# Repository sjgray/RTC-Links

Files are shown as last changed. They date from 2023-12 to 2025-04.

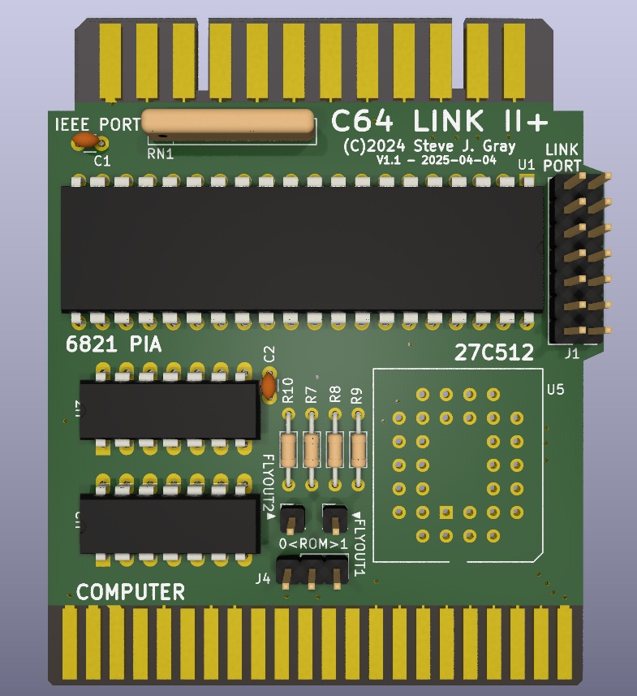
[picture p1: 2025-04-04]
RTC-Link2plus/V1.1/_pics/render.jpg

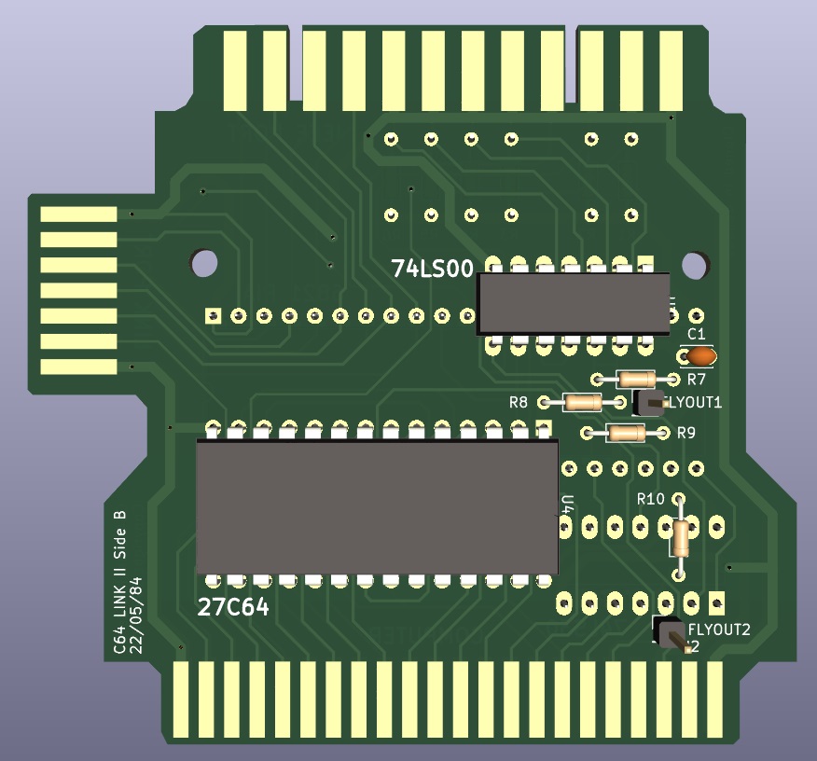
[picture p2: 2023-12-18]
RTC-Link2/_Pics/2023-12-04-render-back.jpg

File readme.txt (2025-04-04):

RTC Link Devices
================

http://www.cbmsteve.ca/
http://www.cbmsteve.ca/rtclinks/index.html

This is a project to clone and improve the Richmond Telecommunications ("RTC") Devices.

RTC released several different devices including:

* V-Link for VIC-20
* V-Link "64" for C64
* Link for C64
* Link-II for C64
* Mult-Link for C64

I personally own both a Link and Link-II, which I would like to clone. I have started with
the Link-II as it has the most features of the two. Also, the Link-II uses a single PCB
with components on both sides.

Link-II
-------

This is a single PCB with components on both sides. It was done this way to make the PCB
as small as possible so it could fit inside an AMP connector shell. There are two flyouts
that are connected internally into the C64 to make the Link more "transparent" which means
that IO and ROM are invisible when not in use. The Link-II also seems to work without these
connections but might have conflicts with other hardware or software.

First step was to de-solder all the components and scan each side. I then flipped the back-side
scan. Kicad was loaded and a new project created. I then loaded the front side and flipped
back-side as images and then added the components. I added global labels for the busses For the
address and data lines etc. I placed the components in their proper places then traced over the
traces on the images to connect the pins, updating labels where necessary.

Status: I will no be ordering PCB's of this design right away. I am concentrating on the PLUS
        version first as it will be easier to populate

Link-II Plus
------------

Once the Link-II was reverse engineered I decided to make a new version but with all components
on the same side making the board easier to build. I replaced the DIP EPROM with a PLCC version,
and some resistors with a resistor network in order to save space. I also replaced the Link
edge-connector with a pin header to allow a more common IDC ribbon cable.

Status: I ordered some V1.0 PCBs. On testing I discovered an error with resistor R9. This was
        corrected manually on the PCB and the board was tested to work properly.
        The design was updated to V1.1 and boards will be made. This should work correctly.        

Future
------

I would like to clone the original Link design but it uses a double-pcb design. I think the
original design would be ok for most people.

Thank-you
---------

Thanks to Walter Miraglia for helping me test and debug RTC-Link II+ V1.0!

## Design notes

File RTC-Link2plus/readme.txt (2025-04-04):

RTC-Link II Plus by Steve J. Gray
================

The RTC-Link II was an IEEE Cartridge for the Commodore C64. It enhanced
C64 BASIC by adding the extra disk commands of BASIC V4, plus a full
machine-language monitor. It also adds a "Link" port which enables
multiple computers to access IEEE devices on a sort-of "network".

The original cartridge is a small and simple IEEE interface using a
single PIA chip. To keep the device small it has components on both
sides of the PCB and is able to be mounted inside an AMP connector shell.

This "plus" version is a re-design that retains the same PCB size but with
all components on one side for an easier build. It retains its small size
by using a PLCC EPROM and resistor pack to reduce the component footprints.
Instead of using an edge connector for the "Link" port this version uses
a normal header. There is an option to have two different firmware
revisions, selectable with a jumper.

Pictures/info can be found at: http://www.cbmsteve.ca/rtclinks/
The GitHub repository is here: https://github.com/sjgray/RTC-Links

History
-------

V1.0 - 2023-12-04 Initial design prototype.
V1.1 - 2025-04-04 Fix for R9. To be tested.

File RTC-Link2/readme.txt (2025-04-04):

RTC-Link II Clone  Reverse Engineered by Steve J. Gray
=================

This is a clone of the RTC-Link II IEEE Cartridge for the Commodore C64.
It also enhances C64 BASIC by adding the extra disk commands of 
Commodore BASIC V4, as well as adding a full machine-language monitor.

The cartridge is a small and simple IEEE interface using a single PIA
chip. To keep the device small it packs in the chip on both sides of the
PCB and is able to be mounted inside an AMP connector shell.

KICAD was used to create a PCB that is very similar to the original and
mounts the components on both sides. I have also created a "plus" version
of the design that retains the same pcb size but with components on one
side, using a PLCC EPROM and resistor pack to reduce the component
footprints. It can also be found on this GitHub repository.

Pictures/info can be found at: http://www.cbmsteve.ca/rtclinks/
The GitHub repository is here: https://github.com/sjgray/RTC-Links

History
-------

V1.0 - 2023-12-04 Initial design prototype. Not tested.
V1.1 - 2025-04-04 Fix for R9. To be tested.

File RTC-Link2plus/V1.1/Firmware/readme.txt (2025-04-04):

RTC Link II Firmware
====================

The Link II+ board supports two different firmware sets in
a 64K EPROM, selectable via the J4 jumper.

The following files are available:

* RTCLINK2.BIN     - Original 8K firmware
* RTCLINK2-MOD.BIN - Modded 8K firmware with alternate power-on message
* RTCLINK2-64K.BIN - Full 64K binary with both sets above.
                     J4: 0=Original, 1=Modded

If you never plan on using a second firmware set you can just burn
either of the first two above to the EPROM and use a jumper wire
to short J4 pin 0 to pin1.

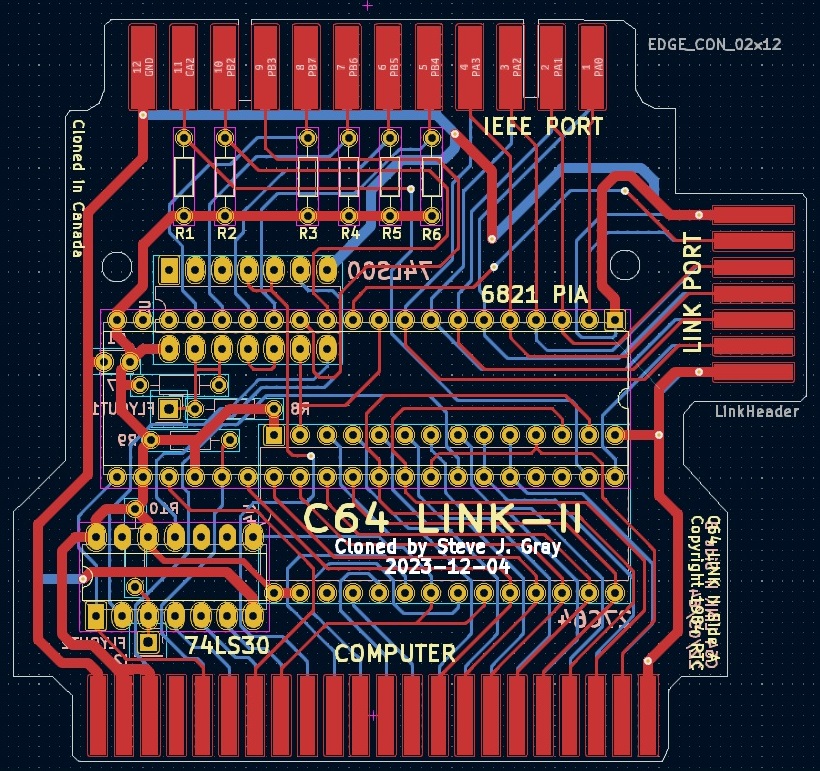
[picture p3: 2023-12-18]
RTC-Link2/_Pics/2023-12-04-routed.jpg

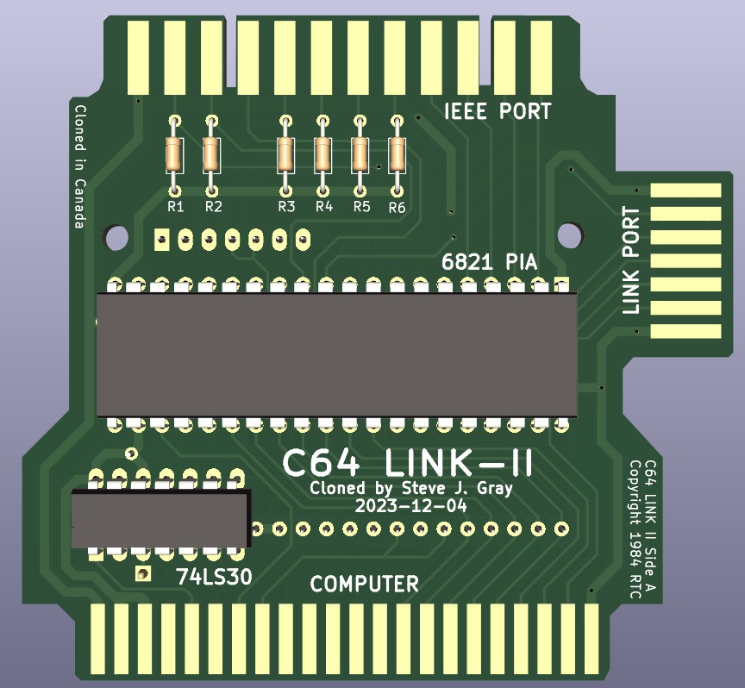
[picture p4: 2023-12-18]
RTC-Link2/_Pics/2023-12-04-render-front.jpg

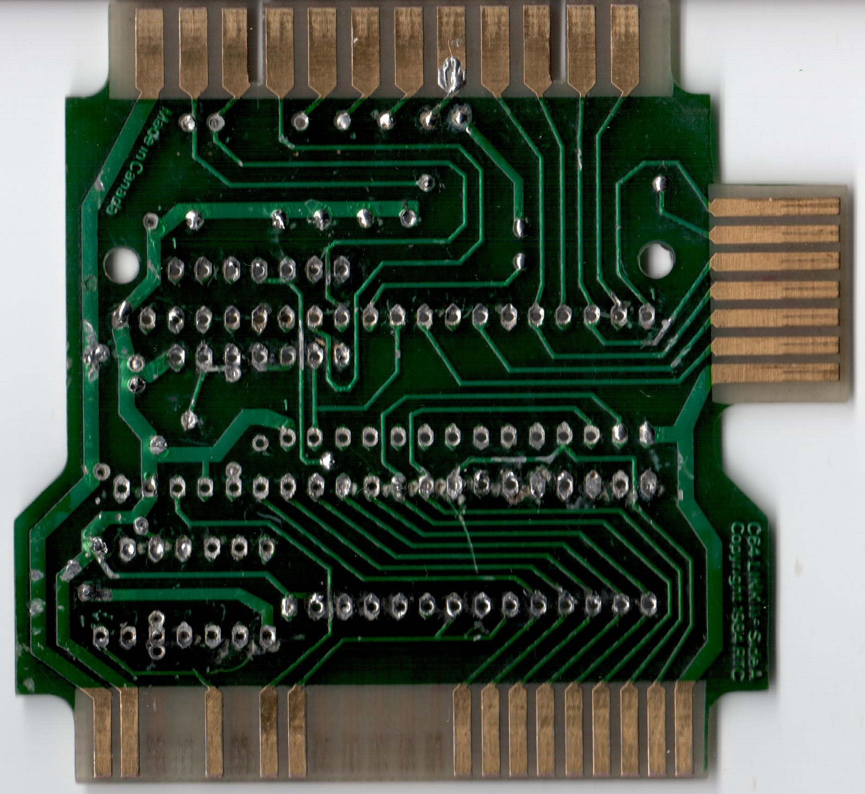
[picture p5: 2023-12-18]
RTC-Link2/rtclink2-pcb-a.jpg

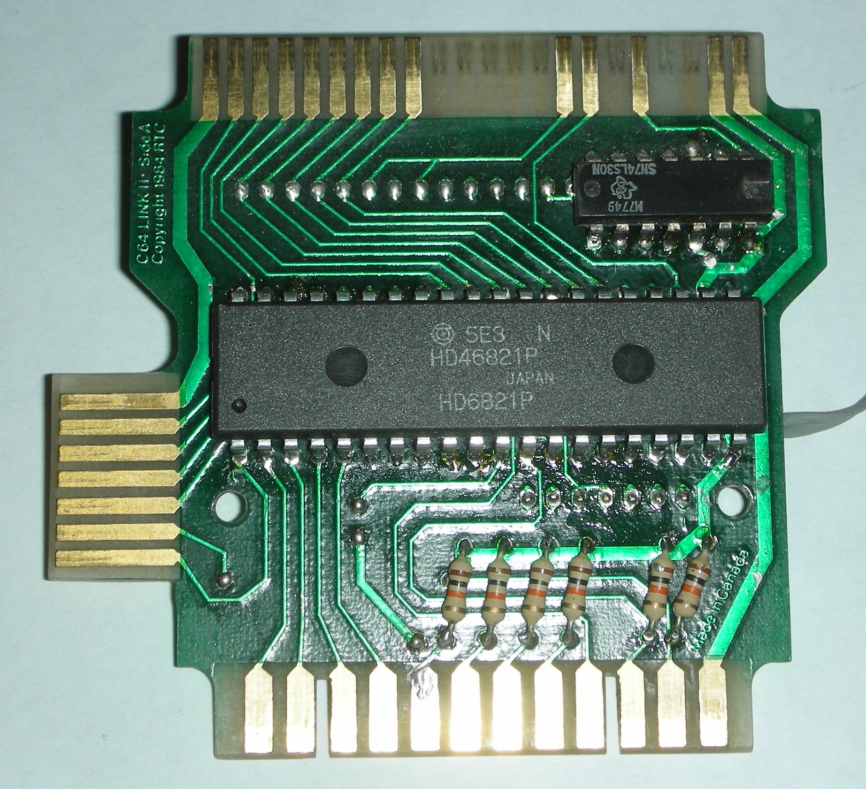
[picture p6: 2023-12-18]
RTC-Link2/rtclink2-top.jpg

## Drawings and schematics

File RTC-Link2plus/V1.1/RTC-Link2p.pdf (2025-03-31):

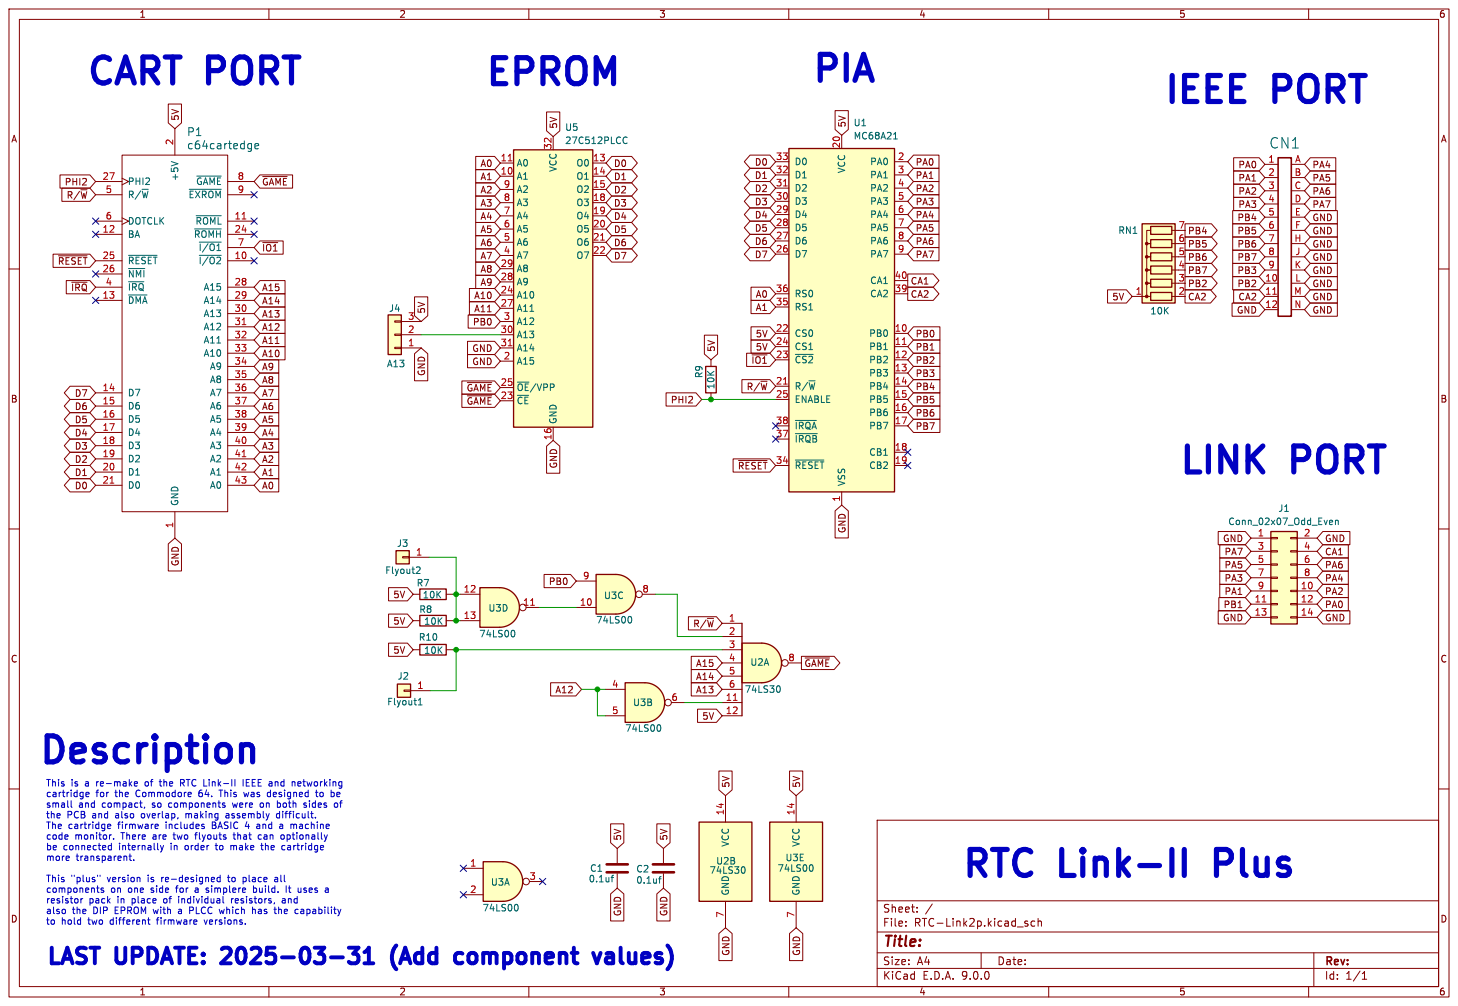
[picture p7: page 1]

IEEE PORT CART PORT

1 ~{GAME} 8 ~{EXROM} 9 ~{ROML}11 ~{ROMH}24 ~{I/O1} 7 ~{I/O2} 10 A15 28 A14 29 A13 30 A12 31 A11 32 A10 33 A9 34 A8 35 A7 36 A6 37 A5 38 A4 39 A3 40 A2 41 A1 42 A0 43 P1

Id: 1/1 Title: File: RTC-Link2p.kicad_sch Sheet: / C1

also the DIP EPROM with a PLCC which has the capability

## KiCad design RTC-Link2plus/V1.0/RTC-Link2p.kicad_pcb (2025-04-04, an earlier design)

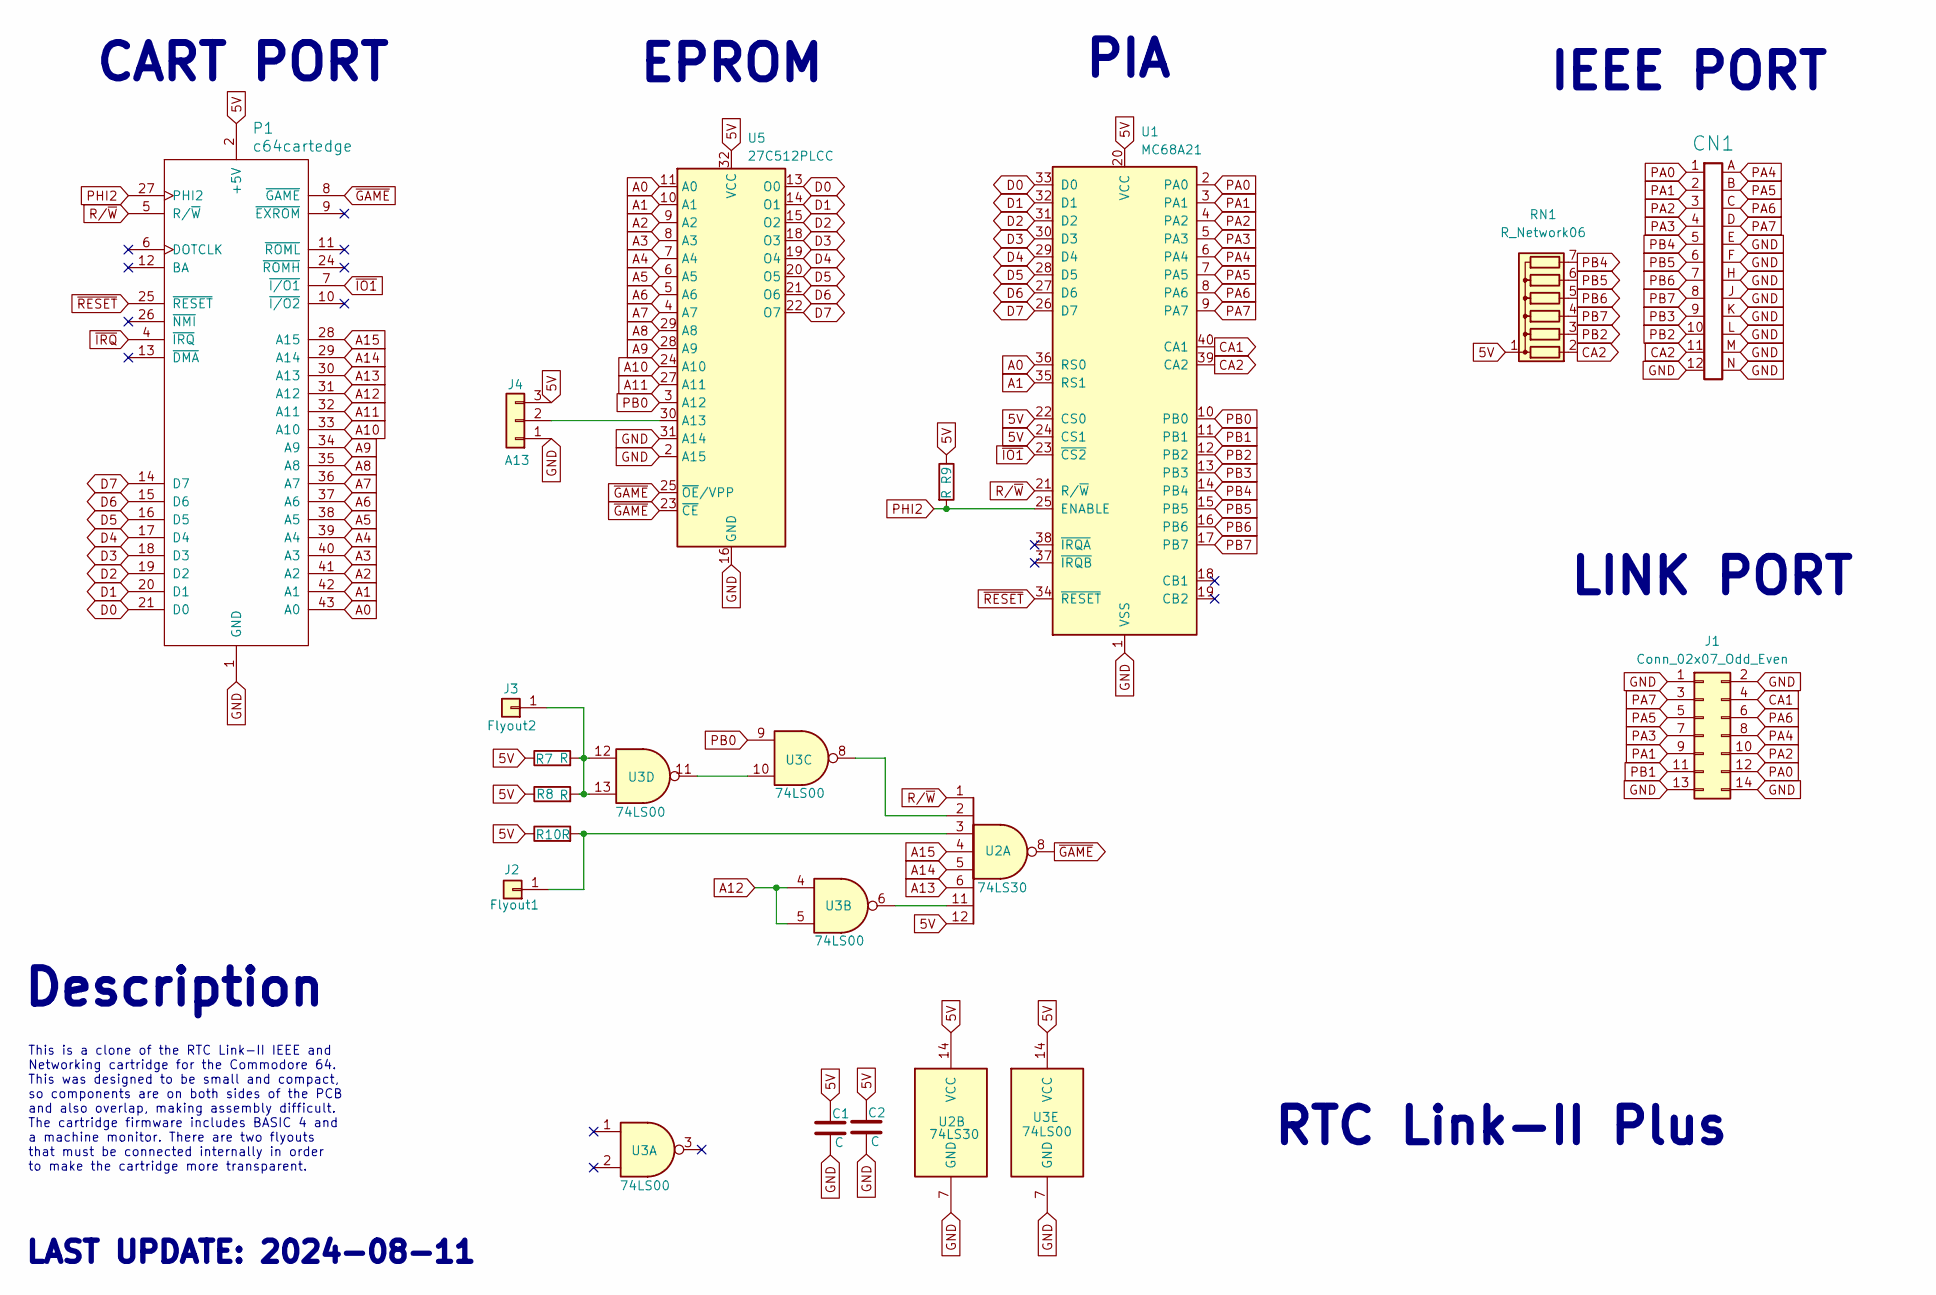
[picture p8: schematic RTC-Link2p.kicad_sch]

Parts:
C1, C2: C; C_Disc_D3.0mm_W1.6mm_P2.50mm
CN1: EDGE_CON_02x12; petieee
J1: Conn_02x07_Odd_Even; PinHeader_2x07_P2.54mm_Vertical
J2: Flyout1; PinHeader_1x01_P2.54mm_Vertical
J3: Flyout2; PinHeader_1x01_P2.54mm_Vertical
J4: A13; PinHeader_1x03_P2.54mm_Vertical
P1: c64cartedge
R7, R8, R9, R10: R; R_Axial_DIN0204_L3.6mm_D1.6mm_P7.62mm_Horizontal
RN1: R_Network06; R_Array_SIP7
U1: MC68A21; DIP-40_W15.24mm
U2: 74LS30; DIP-14_W7.62mm_LongPads
U3: 74LS00; DIP-14_W7.62mm_LongPads
U5: 27C512PLCC; PLCC-32_THT-Socket

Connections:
5V: C1.1, C2.1, J4.3, P1.2 (+5V), P1.3 (+5V), R7.1, R8.1, R9.1, R10.1, RN1.1 (common), U1.20 (VCC), U1.22 (CS0), U1.24 (CS1), U2.12, U2.14 (VCC), U3.14 (VCC), U5.32 (VCC)
A0: P1.43 (A0), U1.36 (RS0), U5.11 (A0)
A1: P1.42 (A1), U1.35 (RS1), U5.10 (A1)
A2: P1.41 (A2), U5.9 (A2)
A3: P1.40 (A3), U5.8 (A3)
A4: P1.39 (A4), U5.7 (A4)
A5: P1.38 (A5), U5.6 (A5)
A6: P1.37 (A6), U5.5 (A6)
A7: P1.36 (A7), U5.4 (A7)
A8: P1.35 (A8), U5.29 (A8)
A9: P1.34 (A9), U5.28 (A9)
A10: P1.33 (A10), U5.24 (A10)
A11: P1.32 (A11), U5.27 (A11)
A12: P1.31 (A12), U3.4, U3.5
A13: P1.30 (A13), U2.6
A14: P1.29 (A14), U2.5
A15: P1.28 (A15), U2.4
CA1: J1.4, U1.40 (CA1)
CA2: CN1.11, RN1.2 (R1), U1.39 (CA2)
D0: P1.21 (D0), U1.33 (D0), U5.13 (O0)
D1: P1.20 (D1), U1.32 (D1), U5.14 (O1)
D2: P1.19 (D2), U1.31 (D2), U5.15 (O2)
D3: P1.18 (D3), U1.30 (D3), U5.18 (O3)
D4: P1.17 (D4), U1.29 (D4), U5.19 (O4)
D5: P1.16 (D5), U1.28 (D5), U5.20 (O5)
D6: P1.15 (D6), U1.27 (D6), U5.21 (O6)
D7: P1.14 (D7), U1.26 (D7), U5.22 (O7)
GND: C1.2, C2.2, CN1.12, CN1.E, CN1.F, CN1.H, CN1.J, CN1.K, CN1.L, CN1.M, CN1.N, J1.1, J1.2, J1.13, J1.14, J4.1, P1.1 (GND), P1.22 (GND), P1.23 (GND), P1.44 (GND), U1.1 (VSS), U2.7 (GND), U3.7 (GND), U5.2 (A15), U5.16 (GND), U5.31 (A14)
unnamed: J2.1, R10.2, U2.3
unnamed: J3.1, R7.2, R8.2, U3.12, U3.13
unnamed: J4.2, U5.30 (A13)
unnamed: U2.2, U3.8
unnamed: U2.11, U3.6
unnamed: U3.10, U3.11
PA0: CN1.1, J1.12, U1.2 (PA0)
PA1: CN1.2, J1.9, U1.3 (PA1)
PA2: CN1.3, J1.10, U1.4 (PA2)
PA3: CN1.4, J1.7, U1.5 (PA3)
PA4: CN1.A, J1.8, U1.6 (PA4)
PA5: CN1.B, J1.5, U1.7 (PA5)
PA6: CN1.C, J1.6, U1.8 (PA6)
PA7: CN1.D, J1.3, U1.9 (PA7)
PB0: U1.10 (PB0), U3.9, U5.3 (A12)
PB1: J1.11, U1.11 (PB1)
PB2: CN1.10, RN1.3 (R2), U1.12 (PB2)
PB3: CN1.9, U1.13 (PB3)
PB4: CN1.5, RN1.7 (R6), U1.14 (PB4)
PB5: CN1.6, RN1.6 (R5), U1.15 (PB5)
PB6: CN1.7, RN1.5 (R4), U1.16 (PB6)
PB7: CN1.8, RN1.4 (R3), U1.17 (PB7)
PHI2: P1.27 (PHI2), R9.2, U1.25 (ENABLE)
R/~W: P1.5 (R/~W), U1.21 (R/~W), U2.1
~GAME: P1.8 (~GAME), U2.8, U5.23 (~CE), U5.25 (~OE/VPP)
~IO1: P1.7 (~I/O1), U1.23 (~CS2)
~IRQ: P1.4 (~IRQ)
~RESET: P1.25 (~RESET), U1.34 (~RESET)

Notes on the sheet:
IEEE PORT
Description
EPROM
LAST UPDATE: 2024-08-11
PIA
This is a clone of the RTC Link-II IEEE and Networking cartridge for the Commodore 64. This was designed to be small and compact, so components are on both sides of the PCB and also overlap, making assembly difficult. The cartridge firmware includes BASIC 4 and a machine monitor. There are two flyo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
CART PORT
RTC Link-II Plus
LINK PORT

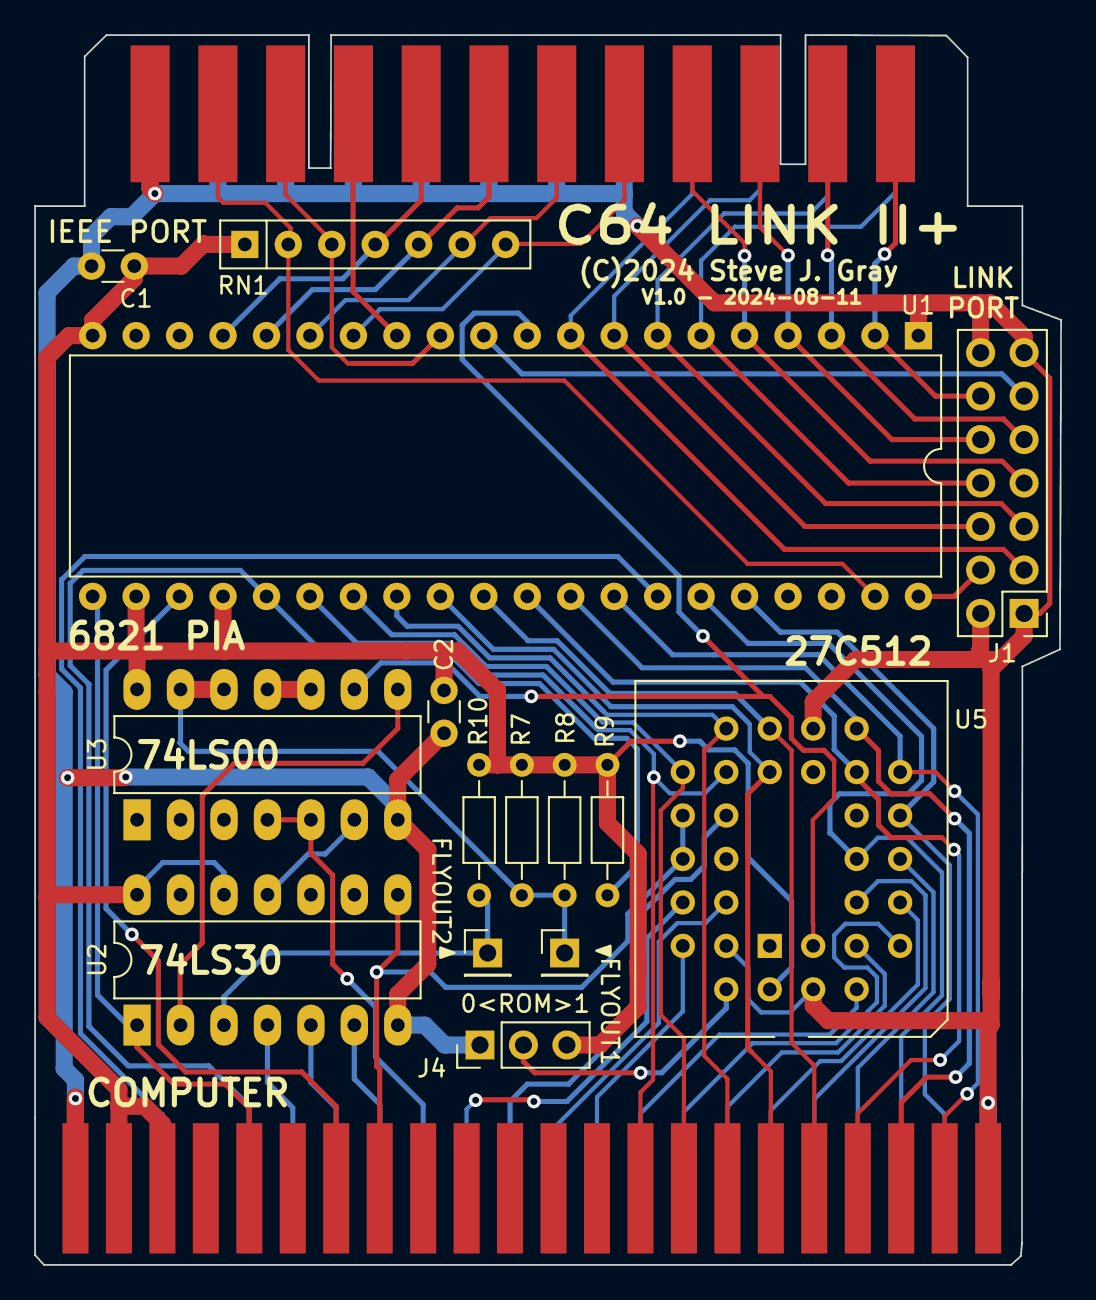
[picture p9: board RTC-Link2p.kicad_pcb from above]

Board: 2 copper layers, 60.0 x 71.9 mm, 17 parts (0 on the bottom side), 55 nets.

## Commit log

2023-12-18 Initial commit. Link-II and Link-II+
    Completed designs for Link-II and Link-II+. Currently there are no gerbers and the designs have not been verified.
    [RTC-Link2.kicad_sch, RTC-Link2p.kicad_pcb, RTC-Link2p.kicad_sch]
2025-03-31 Update to Kicad 9. Add Gerbers, component values, iBom
    Update files to Kicad 9 format. Add Gerbers. Add more component values. Generate interactive BOM. Boards have been made but not tested. Use at own risk!
    [RTC-Link2p-B_Cu.gbr, RTC-Link2p-B_Mask.gbr, RTC-Link2p-B_Paste.gbr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]
2025-04-04 Update original to V1.1. R9 fix.
    I populated the V1.0 "plus" version pcb and discovered an error with R9. It was manually corrected on the pcb and the design works correctly. This original board requires the same fix.
    This V1.1 update **should** work but has not been tested as of yet. Use at own risk!
    Added component values on schematic. Updated files to work on Kicad 9. Added readme file.
    [RTC-Link2-B_Cu.gbr, RTC-Link2-B_Mask.gbr, RTC-Link2-B_Paste.gbr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]
2025-04-04 Release RTC Link II+ V1.1
    V1.0 was built and there was an error with R9. This is now fixed in V1.1. Each version now has it's own folder. Add readme files, interactive BOM. firmware files.
    [RTC-Link2p-B_Cu.gbr, RTC-Link2p-B_Mask.gbr, RTC-Link2p-B_Paste.gbr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]

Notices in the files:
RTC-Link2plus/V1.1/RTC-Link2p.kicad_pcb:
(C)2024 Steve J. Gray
